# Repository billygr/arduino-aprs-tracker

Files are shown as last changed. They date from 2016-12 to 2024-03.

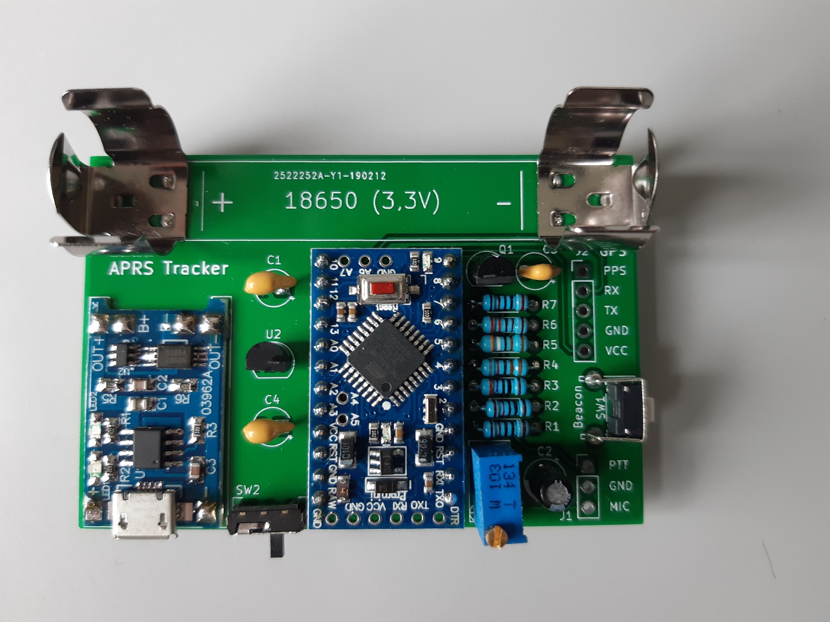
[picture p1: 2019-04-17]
APRS-Tracker_KiCad/Pictures/PCB_soldered_1.jpg

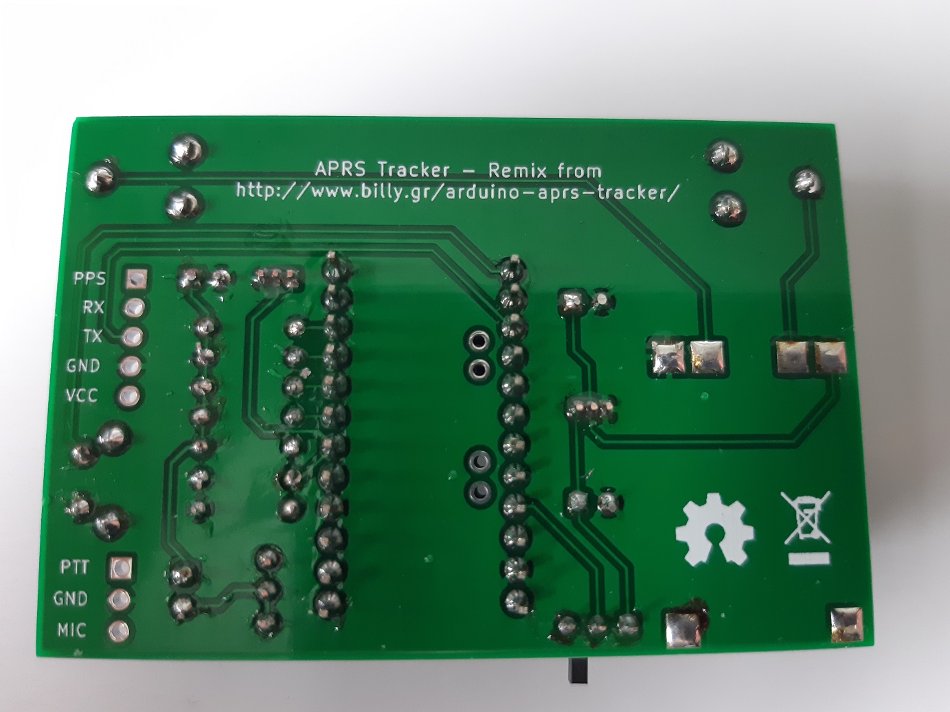
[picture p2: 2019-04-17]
APRS-Tracker_KiCad/Pictures/PCB_soldered_2.jpg

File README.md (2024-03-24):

# arduino-aprs-tracker

Arduino APRS Tracker based on libAPRS with SmartBeaconing

## Hardware
* Arduino Pro Mini 3.3V 8 MHz https://www.adafruit.com/products/2377
* Adafruit Ultimate GPS https://www.adafruit.com/product/746
* or any GPS that can output NMEA (NEO-6M is tested with some minor issues)

## Libraries
* TinyGPS http://arduiniana.org/libraries/tinygps/
* libAPRS (modified) https://github.com/billygr/LibAPRS

## Notes
There are cases where the NEO-6M displays wrong data such as course/altitude. I have trace it to the interrupt of ADC (needed for APRS).
When the interrupt is fired, disrupts the SoftwareSerial so it looses GPS messages.
By default NEO-6M has these messages enabled GSV, RMC, GSA, GGA, GLL, VTG, TXT. 
The GLL is not needed so it is disabled on power on. If you still have issues enable the define, it will switch the NEO-6M on 4800 baud which looks like it fixes it

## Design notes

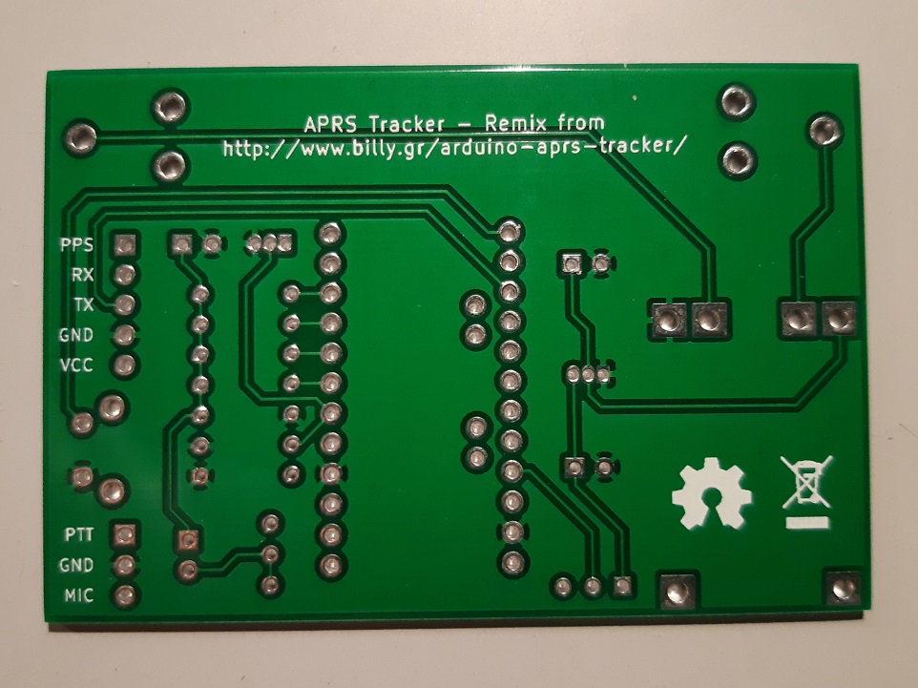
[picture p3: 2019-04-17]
APRS-Tracker_KiCad/Pictures/PCB_2.jpg

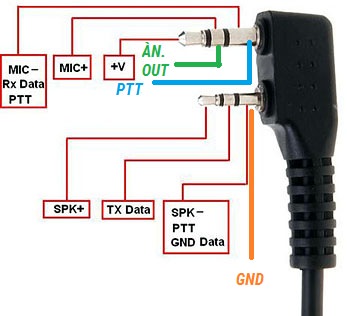
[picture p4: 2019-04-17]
APRS-Tracker_KiCad/Pictures/Baofeng_Plug.jpg

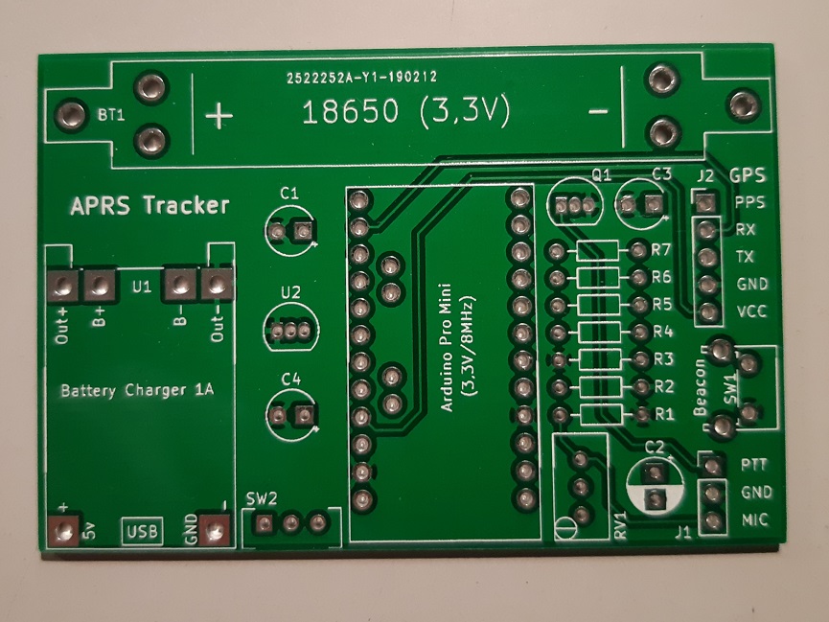
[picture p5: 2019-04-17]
APRS-Tracker_KiCad/Pictures/PCB_1.jpg

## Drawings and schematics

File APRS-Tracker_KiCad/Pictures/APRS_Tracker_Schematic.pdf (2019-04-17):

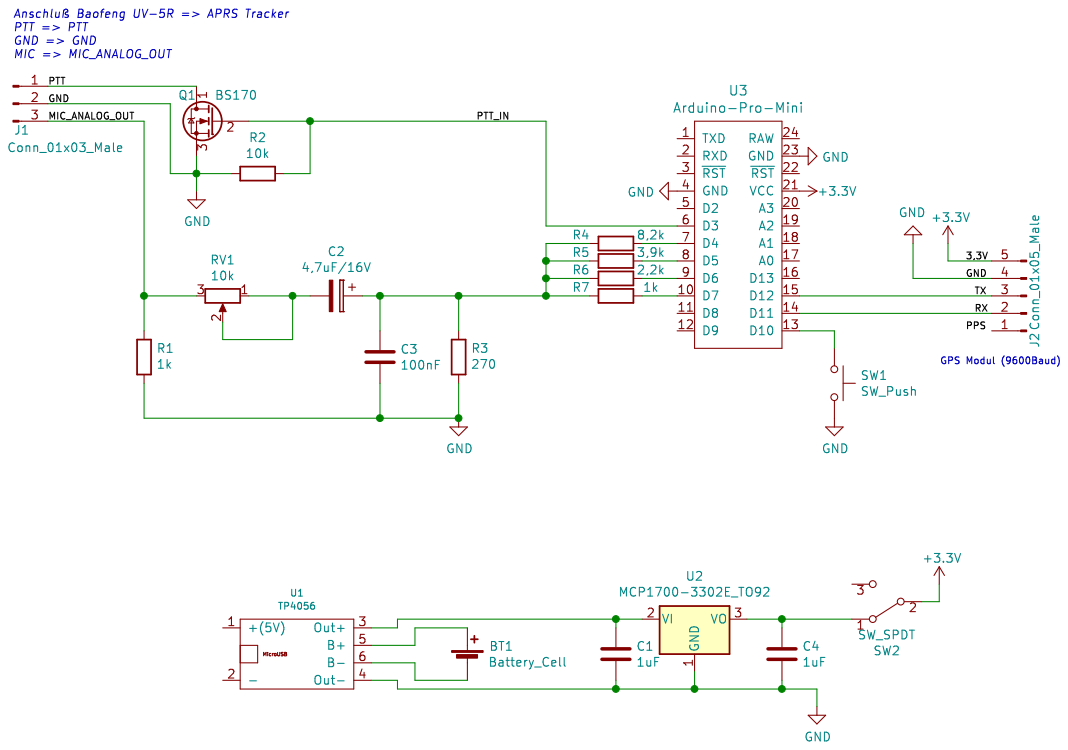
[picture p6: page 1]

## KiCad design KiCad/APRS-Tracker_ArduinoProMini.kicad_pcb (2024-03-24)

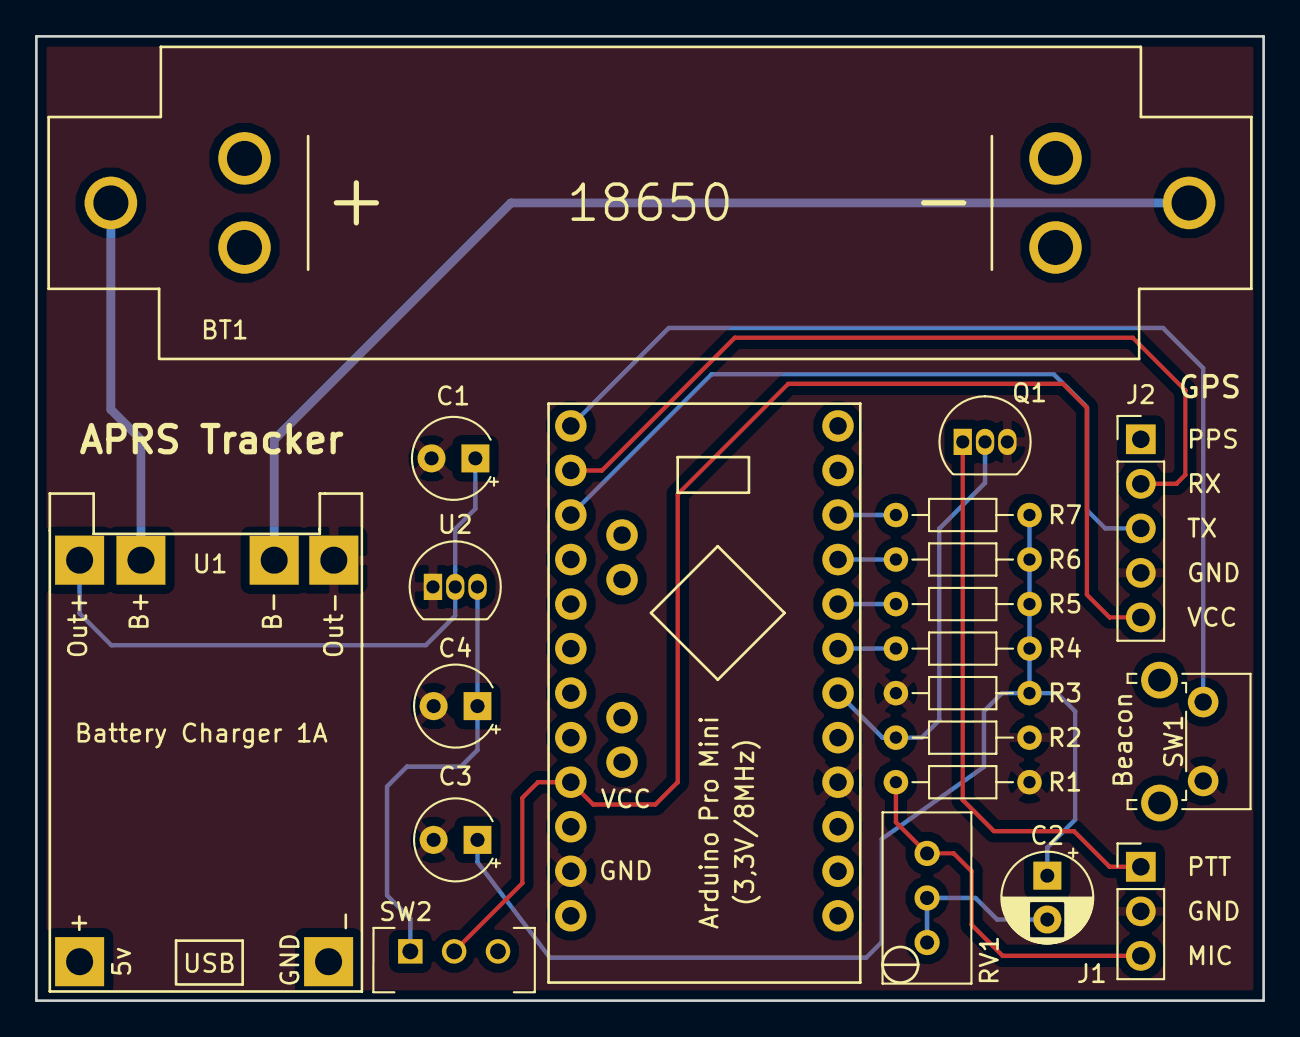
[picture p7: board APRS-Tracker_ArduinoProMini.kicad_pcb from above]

Board: 2 copper layers, 70.0 x 55.0 mm, 21 parts (0 on the bottom side), 18 nets.

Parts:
BT1: Battery_Cell; Battery_ClipHolder_18650
C1, C4: 1uF; CP_Radial_Tantal_D4.5mm_P2.50mm
C2: 4,7uF/16V; CP_Radial_D5.0mm_P2.50mm
C3: 100nF; CP_Radial_Tantal_D4.5mm_P2.50mm
J1: Conn_01x03_Male; PinHeader_1x03_P2.54mm_Vertical
J2: Conn_01x05_Male; PinHeader_1x05_P2.54mm_Vertical
Q1: BS170; TO-92_Inline
R1, R7: 1k; R_Axial_DIN0204_L3.6mm_D1.6mm_P7.62mm_Horizontal
R2: 10k; R_Axial_DIN0204_L3.6mm_D1.6mm_P7.62mm_Horizontal
R3: 270; R_Axial_DIN0204_L3.6mm_D1.6mm_P7.62mm_Horizontal
R4: 8,2k; R_Axial_DIN0204_L3.6mm_D1.6mm_P7.62mm_Horizontal
R5: 3,9k; R_Axial_DIN0204_L3.6mm_D1.6mm_P7.62mm_Horizontal
R6: 2,2k; R_Axial_DIN0204_L3.6mm_D1.6mm_P7.62mm_Horizontal
RV1: 10k; Potentiometer_Bourns_3296W_Vertical
SW1: SW_Push; SW_Tactile_SPST_Angled_PTS645Vx31-2LFS
SW2: SW_SPDT; SW_CuK_JS202011BQN_SPDT_Angled
U1: TP4056; TP4056-18650
U2: MCP1700-3302E_TO92; TO-92_Inline
U3: Arduino-Pro-Mini; Arduino-ProMini

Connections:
+3V3: J2.5, SW2.2, U3.21
/MIC_ANALOG_OUT: J1.3, R1.2, RV1.3
/PTT: J1.1, Q1.1
/PTT_IN: Q1.2, R2.1, U3.6
/RX: J2.2, U3.14
/TX: J2.3, U3.15
GND: C1.2, C3.2, C4.2, J1.2, J2.4, Q1.3, R1.1, R2.2, R3.1, SW1.2, U1.4, U2.1, U3.4, U3.23
unnamed: BT1.1, U1.5
unnamed: BT1.2, U1.6
unnamed: C1.1, U1.3, U2.2
unnamed: C2.1, C3.1, R3.2, R4.2, R5.2, R6.2, R7.2
unnamed: C2.2, RV1.1, RV1.2
unnamed: C4.1, SW2.1, U2.3
unnamed: R4.1, U3.7
unnamed: R5.1, U3.8
unnamed: R6.1, U3.9
unnamed: R7.1, U3.10
unnamed: SW1.1, U3.13

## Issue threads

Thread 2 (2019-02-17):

APRS tracker without GPS module

cookins, 2019-02-17:
Hey there!
Im not exactly programmer, so can somebody help me to edit code for manual GPS coords just.
For me its not necessary to update GPS coords, cuz device located in same spot all time.
Thank you.

billygr, 2019-02-23:
Looking at the code you will need a lot of changes, do you need just one update or updates over fixed intervals ?

cookins, 2019-02-23:
just fixed coords. for all time stationary location.
without GPS module of course.

billygr, 2019-02-24:
Here you go compile test only
https://github.com/billygr/aprs-tracker-without-gps-module

cookins, 2019-02-24:
Thank you :kissing_heart:

Closed 2019-02-24.

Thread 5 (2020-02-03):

How to change aprs beacon timer?

kovalroma, 2020-02-03:
Hello,
I found that tracker send beacon every 1 minutes.
Is it possible to change it to 30 seconds ?
I've changed this line
```
 #define TIMER_MINUTES 30L*1000L
```
But it didn't help.

billygr, 2020-02-04:
Hi ,

you can change directly the interval on this line

aprs_update_timer_id=timer.setInterval(2*TIMER_MINUTES, setAprsUpdateFlag)

Replace 2*TIMER_MINUTES with 30000. I would recommend to go so low , it is way to fast and you will fill the APRS network with messages

kovalroma, 2020-02-04:
Thank you so much!

Closed 2020-02-04.

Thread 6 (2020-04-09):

Timer

Wosacz, 2020-04-09:
Hello, May I have a question about your "timer"? Is it the way how to fix APRS and GPS modul with their problems work together? How it work?

billygr, 2020-04-10:
Hi, I don't understand exactly the question. If you have a GPS fix the timer just fires up and send an APRS location

Closed 2020-07-30.

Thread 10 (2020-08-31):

SmartBeaconing is sending invalid packets after long time continuous working

kovalroma, 2020-08-31:
Hello,
We have tested new SmartBeaconing feature (tested on 2 devices) during long time (few days) continuous work.
We found very strange issues.

During first several days all sending correctly. But later we found that trackers send invalid data
` -9>APZMDM,WIDE1-1,WIDE2-2,qAR,UR5KSH-1:=5036.75N/02614.07E>/A=000746Arduino APRS Tracker `
Should be
` UR5KSH-9>APZMDM,WIDE1-1,WIDE2-2,qAR,UR5KSH-1:=5036.75N/02614.07E>/A=000746Arduino APRS Tracker `

And the second tracker
` UR5KHL-9>APZMDM,UR5KSH-1,WIDE1*,WIDE2-2,qAO,UR5KDK-2:=5044.37N/02603.18E>-16/60/A=000670Arduino APRS Tracker `
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

To fix invalid behavior I restarted device.

I think this error someway connected with buffer overload.

billygr, 2020-09-03:
Still checking it, thanks for reporting it

kovalroma, 2020-09-17:
Was it possible to reproduce the error?

billygr, 2020-09-20:
Nope, i reset it today and will let it there running for 48h again (stationery)

kovalroma, 2020-09-20:
In our case bug appears after 7 days. So, maybe 48h would be not enough.

kovalroma, 2020-10-30:
Hello @billygr
Any news? Does only our setup has such kind of problem? If yes maybe we need to try to change Arduino board.

billygr, 2020-10-30:
Hi,

It is software related for sure but i cannot trace it. What is the Arduino IDE version you are using ? Can you please try with the latest ?

kovalroma, 2021-01-21:
Good morning, hope you are doing well.
After long time we found what's cause problem of irregular distance.
Definitely something wrong with GPS data.

Please look here, this is Arduino terminal:

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

Sometimes GPS send incorrect coordinates (putting zero) to Arduino:
```
Lat: correct_data Lon: 0.00000
Lat: 0.00000 Lon: 0.00000
```

In theory any object could be in such position, but in practice this is almost impossible. Maybe it's good idea to add additional check ? I will explain what I mean.
For instance if distance between 2 coordinates more than 100 km, it's mean that something wrong with GPS data, and in this case just ignore such packet ? Almost all our tracker (3 pieces) has such type of bug.

In additional. The same hardware (Arduino, GPS) works create in previous firmware, without SmartBeacon, where only interval beaconing send. Maybe this problem somehow connected with continuous data transmission between Arduino and GPS in case of SmartBeaconing and interval data transmission in case of interval beaconing ?

Today we are going to upload firmware with latest Arduino and library. I'll let you know about the results.

billygr, 2021-01-22:
Got it , it looks like the invalid is always 0.0000 let me work with it over the weekend and drop this type of location when they arrive from the GPS

kovalroma, 2021-01-22:
This is packet from aprsdirect.com RAW mode. I think at least Lat or Lon is 0.0000.
```
UR5KSH-9>APZMDM,WIDE1-1,WIDE2-2,qAR,UR5KSH-1:=0000.00N/00004.00E>-48/03/A=000662Arduino APRS Tracker
 ```

billygr, 2021-01-22:
Thank you, and the code is from the SmartBeacon branch ?

kovalroma, 2021-01-22:
> Thank you, and the code is from the SmartBeacon branch ?

Yes. It's from SmartBeacon branch.  Master branch works without bugs.

kovalroma, 2021-01-22:
Here is also invalid packet. Retransmitted by several Digipeater, but anyway

```
22.01.2021 20:43:36+01:00: UR5KHL-9>APZMDM,UR5KSH-1*,WIDE1*,UR4PWJ-1*,WIDE2-1,qAS,UR3PDA-9:=5037.58N/02614.70E>-30/70
```

```
22.01.2021 20:46:44+01:00: UR5KHL-9>APZMDM,UR5KSH-1,WIDE1,UR4PWJ-1*,WIDE2-1,qAS,UR3PDA-9:=5037.58N/02614.71E>-10/06
```

This ` -30/70 ` and `-10/06 ` . But should be ` /A=004200 `
It seams that coordinates is correct, but why ` char APRS_comment [36]="/A="; `  was changed? This is mysterious.

kovalroma, 2021-01-24:
Please take a look on this packet
```
UR5KHL-9 to APZMDM-0 via WIDE1-1,WIDE2-2 UI  PID=F0 5037.58N/02614.70E>-22/23./A=004200Arduino APRS Tracker. V=13.5
```
This is decoded APRS packet. After 6 hours we have lot's of packet's with incorrect course and speed data.
This ` -22/23./ ` should be represented as ``` 000/000 or .../... or VVV/VVV ```

APRS reference:
```
The 7-byte CSE/SPD Data Extension can be used to represent the course and
speed of a vehicle or APRS Object.
The course is expressed in degrees (001-360), clockwise from due north. The
speed is expressed in knots. A slash / character separates the two.
For example:
 088/036 represents a course 88 degrees, traveling at 36 knots.
If the course and speed are unknown or not relevant, they can be set to
000/000 or .../... or VVV/VVV.
```
I found that this data are based on following expressions
https://github.com/billygr/arduino-aprs-tracker/blob/de4ff6c1971c3560d853e6b98d39e82cd3298869/arduino-aprs-tracker/arduino-aprs-tracker.ino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

https://github.com/billygr/arduino-aprs-tracker/blob/de4ff6c1971c3560d853e6b98d39e82cd3298869/arduino-aprs-tracker/arduino-aprs-tracker.ino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

But I am not sure,  ` gps.f_course() ` calculated on Arduino with ` TinyGPS ` or this is just received data from satellite ?

kovalroma, 2021-01-24:
This is from TiniGPS
```
case COMBINE(_GPS_SENTENCE_GPRMC, 8): // Course (GPRMC)
      _new_course = parse_decimal();
```
Can you confirm that ` speed_kt ` is received from GPS module. So, Arduino received speed and course in GPRMC message which was calculated on GPS module compute system ?

billygr, 2021-01-25:
Hi,

Let's try to fix it one step at a time. I have added a small check for lat if 0 it will be ignored
Can you please confirm that it is working as expected ?

kovalroma, 2021-01-25:
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

Hey, thanks! I will check new code and let you know.

BTW, we use [Neo-6m GPS module](https://www.u-blox.com/sites/default/files/products/documents/NEO-6_DataSheet_(GPS.G6-HW-09005).pdf). This is quite similar, to Adafruit Ultimate GPS. But much more cheaper.

Also I found this [library ](https://github.com/SlashDevin/NeoGPS) dedicated to work with our hardware.

billygr, 2021-01-25:
Hi,

I am waiting for a one Neo-6m. Use whatever is available, there is a chance that are fake (if coming from china) but still they work . I will look over this code maybe it will help to reduce the ram usage (needed for LibAPRS)

Billy

kovalroma, 2021-01-26:
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

We bought Neo-6m on Aliexpress, so definitely fake. But nevertheless they correctly work with [U-Center](https://www.u-blox.com/en/product/u-center).

Here is our APRS log with new firmware after 8 hours.
For example randomly 10 minutes from 9:30 to 9:40. We got 16 packet.

Problem with incorrect coordinates not found.

Problem with incorrect course/speed is found.
11 packet are correct,
5 packet are not correct.

All the time Arduino is connected and doesn't move.

```
26.01.2021 09:30:10+01:00: UR5KHL-9>APZMDM,WIDE1-1,WIDE2-2,qAR,UR5KSH-1:=5037.59N/02614.71E>/A=004200Arduino APRS Tracker

26.01.2021 09:30:40+01:00: UR5KHL-9>APZMDM,WIDE1-1,WIDE2-2,qAR,UR5KSH-1:=5037.59N/02614.71E>-31/35/A=004200Arduino APRS Tracker

26.01.2021 09:30:43+01:00: UR5KHL-9>APZMDM,UR5KSH-1,WIDE1,UR4PWJ-1*,WIDE2-1,qAS,UR3PDA-9:=5037.59N/02614.71E>-31/35

26.01.2021 09:31:09+01:00: UR5KHL-9>APZMDM,WIDE1-1,WIDE2-2,qAR,UR5KSH-1:=5037.59N/02614.70E>/A=004200Arduino APRS Tracker

26.01.2021 09:31:58+01:00: UR5KHL-9>APZMDM,WIDE1-1,WIDE2-2,qAR,UR5KSH-1:=5037.59N/02614.69E>/A=004200Arduino APRS Tracker

26.01.2021 09:33:28+01:00: UR5KHL-9>APZMDM,WIDE1-1,WIDE2-2,qAR,UR5KSH-1:=5037.59N/02614.71E>/A=004200Arduino APRS Tracker
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
kovalroma, 2021-03-23:
Here full log from second attempt :) .  Chinese GPS module Neo-M8N.

[aprs-log-chines-module-gps.txt](https://github.com/billygr/arduino-aprs-tracker/files/6192439/aprs-log-chines-module-gps.txt)

billygr, 2021-03-24:
i think that you have got fakes, the position jumps as i can see it on the log.

Is it always after 30 minutes ? I mean you can reproduce it  ?

kovalroma, 2021-03-25:
> Is it always after 30 minutes ? I mean you can reproduce it ?

Not sure, will check again.
Meanwhile attached log from [smartbeaconing ](https://github.com/billygr/arduino-aprs-tracker/tree/smartbeaconing)tree with branded Velleman VMA430.
[aprs-log-Velleman VMA430.txt](https://github.com/billygr/arduino-aprs-tracker/files/6206907/aprs-log-Velleman.VMA430.txt)

The same bug after 25/3/2021 17:3:58.
The last digit here
` 25/3/2021 17:4:4 LAT=52150757 LON=21056484 5209.04N/02103.38E Altitude m/ft: 104.80/225`
is `currentcourse`.

kovalroma, 2021-03-25:
This log after I press reset button on arduino
```
25/3/2021 18:8:48 LAT=52150762 LON=21056485 5209.04N/02103.38E Altitude m/ft: 120.40/0
25/3/2021 18:8:49 LAT=52150761 LON=21056483 5209.04N/02103.38E Altitude m/ft: 120.60/0
25/3/2021 18:8:50 LAT=52150761 LON=21056481 5209.04N/02103.38E Altitude m/ft: 120.70/0
25/3/2021 18:8:51 LAT=52150761 LON=21056480 5209.04N/02103.38E Altitude m/ft: 120.90/0
25/3/2021 18:8:52 LAT=52150760 LON=21056479 5209.04N/02103.38E Altitude m/ft: 121.10/0
25/3/2021 18:8:54 LAT=52150760 LON=21056476 5209.04N/02103.38E Altitude m/ft: 121.10/0
25/3/2021 18:8:55 LAT=52150760 LON=21056475 5209.04N/02103.38E Altitude m/ft: 121.50/0
25/3/2021 18:8:56 LAT=52150760 LON=21056475 5209.04N/02103.38E Altitude m/ft: 121.60/0
25/3/2021 18:8:57 LAT=52150760 LON=21056474 5209.04N/02103.38E Altitude m/ft: 121.70/0
25/3/2021 18:8:58 LAT=52150761 LON=21056473 5209.04N/02103.38E Altitude m/ft: 121.80/0
25/3/2021 18:8:59 LAT=52150761 LON=21056473 5209.04N/02103.38E Altitude m/ft: 122.00/0
25/3/2021 18:9:0 LAT=52150761 LON=21056473 5209.04N/02103.38E Altitude m/ft: 122.10/0
25/3/2021 18:9:1 LAT=52150762 LON=21056473 5209.04N/02103.38E Altitude m/ft: 122.10/0
```

Take a look to time stamp.

After I press reset 3 times, it changed to normal
```
25/3/2021 18:11:41 LAT=52150802 LON=21056440 5209.04N/02103.38E Altitude m/ft: 128.30/0
25/3/2021 18:11:42 LAT=52150803 LON=21056439 5209.04N/02103.38E Altitude m/ft: 128.20/0
25/3/2021 18:11:43 LAT=52150803 LON=21056438 5209.04N/02103.38E Altitude m/ft: 128.10/0
25/3/2021 18:11:44 LAT=52150803 LON=21056437 5209.04N/02103.38E Altitude m/ft: 128.00/0
```

kovalroma, 2021-03-25:
Yes, I can reproduced with Velleman VMA430 and [smartbeaconing ](https://github.com/billygr/arduino-aprs-tracker/tree/smartbeaconing) tree.

billygr, 2021-03-26:
i did a long run while displaying the free memory , no mem leaks, of course that doesn't solve you problem

Can you please check this ? https://portal.u-blox.com/s/question/0D52p00008HKEEECA5/psa-fake-ublox-modules-and-potential-ways-to-identify-them mainly the GPTXT

kovalroma, 2021-03-30:
From Velleman VMA430
```
$GPTXT,01,01,02,u-blox ag - www.u-blox.com*50
$GPTXT,01,01,02,HW  UBX-G70xx   00070000 FF7FFFFFo*69
$GPTXT,01,01,02,ROM CORE 1.00 (59842) Jun 27 2012 17:43:52*59
$GPTXT,01,01,02,PROTVER 14.00*1E
$GPTXT,01,01,02,ANTSUPERV=AC SD PDoS SR*20
$GPTXT,01,01,02,ANTSTATUS=OK*3B
$GPTXT,01,01,02,LLC FFFFFFFF-FFFFFFFF-FFFFFFFF-FFFFFFFF-FFFFFFF9*51
```

kovalroma, 2021-03-30:
Chinese module
```
$GNTXT,01,01,02,u-blox AG - www.u-blox.com*4E
$GNTXT,01,01,02,HW UBX-M8030 00080000*60
$GNTXT,01,01,02,EXT CORE 3.01 (d189ff)*68
$GNTXT,01,01,02,ROM BASE 3.01 (107888)*25
$GNTXT,01,01,02,FWVER=ADR 4.11*53
$GNTXT,01,01,02,PROTVER=19.10*11
$GNTXT,01,01,02,MOD=NEO-M8L-0*65
$GNTXT,01,01,02,FIS=0xEF4015 (100111)*58
$GNTXT,01,01,02,GPS;GLO;GAL;BDS*77
$GNTXT,01,01,02,SBAS;IMES;QZSS*49
$GNTXT,01,01,02,GNSS OTP=GPS;GLO*37
$GNTXT,01,01,02,LLC=FFFFFFFF-FFFFFFFF-FFFFFFFF-4FFFFF7E-FFFFFF49*20
$GNTXT,01,01,02,ANTSUPERV=AC *00
$GNTXT,01,01,02,ANTSTATUS=OK*25
$GNTXT,01,01,02,PF=3F7*3A
```

billygr, 2022-03-05:
Just an update.

The issue is not related on your GPS but on the code it self. Yes it reproduce on my NEO-6M also, but only on this device type

It was traced down to the ADC interrupt killing the software serial so it was missing GPS data. I have updated it for the smartbeaconing branch will do the same also here.

billygr, 2024-03-24:
Merged the smartbeaconing branch to master including the fixes

Closed 2024-03-24.

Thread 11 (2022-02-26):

Error in height and continuous sending of packets

ghost, 2022-02-26:
Hello, I see that the height error is a recurring theme. If I load the TinyGPS IDE example, the readings are correct, but with the smartbeaconing code it always shows me 1000000. I guess it could be an error with the data reading or conversion, at one point I put some serialprintln and it started to show me fine, but it didn't last long and it was gone.

Regarding the continuous sending of packets, it enters the update loop and has a hard time getting out, I could see that the course of being in normal values, goes to a negative value and 5 figures.

I currently use a 3.3v Pro mini board and a NEO6

Greetings

billygr, 2022-02-27:
Could you please so kind and test the TinyGPSPlus branch ? It contains the smartbeaconing code but i have not done any real tests. Eventually i will switch to this library in any case

billygr, 2022-02-27:
Can you please check the recent update on the smartbeaconing branch ?

We will be able to narrow it down

billygr, 2022-02-27:
Ok

Two different topics:
Altitude 1000000 comes from TinyGPS when the Altitude is invalid
Course 1000 if the course is invalid

I tried to fix the course issue, in the latest update. I was able to reproduce it locally but now my GPS is not giving a valid course (inside the house) to confirm it

aledorrego, 2022-02-28:
I just uploaded the smartbeaconing update. The continuous sending of packets problem was apparently solved, it only fires eventually by turning, but being without movement. The height still shows 1000000.
If I load the example from the TinyGPS IDE it shows me the height fine.
I currently use IDE 1.8.15
You can see me on aprs.fi as LW7EEA-7

billygr, 2022-03-01:
When stationary the GPS cannot provide a valid course (it jumps left,right) so it will get fired randomly.

The height is not valid that's why you get a 1000000. Will fix that also by ignoring this values

aledorrego, 2022-03-02:
I keep doing tests.

When I uncomment this line

   // Serial.write(c); // uncomment this line if you want to see the GPS data flowing

I see the data that the GPS extracts, but the GPGGA sentence is not seen, which is the one that throws the height and satellite data.

On the other hand, if I uncomment this line

  // uncomment this line to turn on RMC (recommended minimum) and GGA (fix data) including altitude
  //GPS.sendCommand(PMTK_SET_NMEA_OUTPUT_RMCGGA);

it gives me compilation error.

billygr, 2022-03-02:
I have pushed another update to the smartbeaconing branch 5 minutes ago. Can you please do another test ? its more clean/better output etc

billygr, 2022-03-02:
Yes and it will stay in that loop till the altitude is correct

aledorrego, 2022-03-02:
it's fine. comment out that loop, and the height keeps reading 1000000 for many minutes.
Are you sure the library is reading the GPGGA statement?

billygr, 2022-03-02:
Yeap, no changes on the library. It is what TinyGPS reports, the value of 1000000 means invalid altitude

aledorrego, 2022-03-02:
okay.  I don't know what is causing the error in altitude.  when I load the example from the TinyGPS IDE I get the altitude fine and instantly.  That's why I thought that the GPS was not getting all the data.  When I do a c serialprint, which would be the raw GPS data, I never see the GGA statement, nor do I see the height and satellite values.  but well, I appreciate your time and predisposition to try to solve it.  a hug and thanks

billygr, 2022-03-03:
First of all thanks for the hug !!!. I can reproduce it with a NEO 6M here, and i think it is a matter of timing (processing data from the module). The reason the TinyGPS example that it is working is that it is pretty simple.

After a reset of the arduino, even with the GPS on a fix, i will get a lot of lines with 255 satellites and invalid latitude

Still looking at it

billygr, 2022-03-03:
The issue is the RAM usage, excluding the libaprs part the code behaves as expected (so your GPS it not faulty)

billygr, 2022-03-05:
Updated.

Not RAM usage but the ADC ISR killing the SoftwareSerial... give it a try

Its not the best solution to reduce the speed of the GPS to 4800 but it is more stable

aledorrego, 2022-03-05:
Well, I just uploaded the new code, but unfortunately it's still the same.

Do not worry

03/05/2022 12:53:18 -38.726333-61.287624 0.00   0.19  3843.57S/06117.25W 1000000.00/4200 0 0 1325
03/05/2022 12:53:19 -38.726333-61.287624 0.00   0.15  3843.57S/06117.25W 1000000.00/4200 0 0 1649
03/05/2022 12:53:20 -38.726333-61.287624 0.00   0.11  3843.57S/06117.25W 1000000.00/4200 0 0 2189
03/05/2022 12:53:21 -38.726333-61.287624 0.00   0.37  3843.57S/06117.25W 1000000.00/4200 0 0 677
03/05/2022 12:53:23 -38.726337-61.287624 0.00   0.13  3843.58S/06117.25W 1000000.00/4200 0 0 1881
03/05/2022 12:53:26 -38.726337-61.287624 0.00   0.22  3843.58S/06117.25W 1000000.00/4200 0 0 1109
03/05/2022 12:53:27 -38.726337-61.287624 0.00   0.11  3843.58S/06117.25W 1000000.00/4200 0 0 2189
03/05/2022 12:53:29 -38.726337-61.287628 0.00   0.00  3843.58S/06117.25W 1000000.00/4200 0 0 0
03/05/2022 12:53:30 -38.726337-61.287624 0.00   0.54  3843.58S/06117.25W 1000000.00/4200 0 0 476

billygr, 2022-03-05:
Give it some time and eventually the 1000000 altitude gets fixed

aledorrego, 2022-03-05:
I have no luck, more than 30 minutes working and still the same.

billygr, 2022-03-06:
Give it a try with 4800 baud, mine is sitting on my desk and recovers after 2-3 minutes

aledorrego, 2022-03-06:
Ok. Intentaré nuevamente. Entendí que la última actualización ya estaba en 4800, no es así? Lo cargue tal cual está en el archivo. O te lo que modificar algo?

billygr, 2022-03-06:
Only if you remove the comments from the define neo-6m. If you want to revert it to 9600 you will need to power cycle it (after disabling the define again )

aledorrego, 2022-03-06:
Now yes my friend!!!! After so much work it works!!! what a genius....
Now I can see the height and the number of satellites I receive without problems. In fact this last update improved the course, no more high values are seen.
I am going to work on showing in the APRS comment, instead of the height in feet, that it shows me the number of satellites.
Very grateful for all your time and wisdom, it's really a pleasure to have dealt with you.

billygr, 2022-03-07:
Just remember that it is a workaround for the real issue . At least you have something to play with

billygr, 2024-03-24:
Merged smartbeaconing including the workaround to master

Closed 2024-03-24.

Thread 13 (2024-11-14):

I'm having trouble at PTT

uguraltinsoy, 2024-11-14:
I am using the LibAPRS library and my problem is that the default PTT time is too short and the signal is not fully transmitted. How can I bypass it and make my own continuous TX, the signal is much cleaner.

https://www.youtube.com/watch?v=PrCiLKZh58M

billygr, 2024-11-16:
Give it a try with the Preamble and Tail on the void setup
// APRS_setPreamble(350);
// APRS_setTail(50);

uguraltinsoy, 2024-11-17:
Jeg tester ved hjælp af soundmodem og afsk1200dec, men der er ingen forbedring, desværre spekulerer jeg på, om det ikke fungerer for mig, jeg rejste også i byen i det åbne område, jeg kan ikke falde til APRS.fi

billygr, 2024-11-17:
Can you please use English on your comments ? Thank you

uguraltinsoy, 2024-11-17:
Sorry, I am testing using soundmodem and afsk1200dec, but there is no improvement, unfortunately, I wonder if it is not working for me, I also traveled in the open area in the city, it does not fall to APRS.fi

uguraltinsoy, 2024-11-17:
They are connected to the same ground line

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

billygr, 2024-11-17:
Give it a try by grounding manually the PTT on the module and press BUTTON_PIN 10 for a manual update on the Arduino

If it works correctly you will see your message on the aprs.fi . and the problem is beetween the PTT and the Arduino.

I assume that you see the messages on the serial of Arduino , right ?

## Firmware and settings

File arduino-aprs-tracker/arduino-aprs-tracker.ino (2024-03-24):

/***
 * Arduino APRS Tracker (aat) with Arduino Pro Mini 3.3V/8 MHz
 * Install the following libraries through Arduino Library Manager
 * - TinyGPS by Mikal Hart
 * -
 * -
 ***/

#include <SoftwareSerial.h>
#include <TinyGPS.h>
#include <LibAPRS.h>

// Enable this define NEO6M if you are constantly getting wrong data,
// the ADC ISR triggers during SoftwareSerial so we miss data coming from GPS
// (for some reason only on this type of GPS and only when running on 9600 bps)
//#define NEO6M

// Manual update button
#define BUTTON_PIN 10

// GPS SoftwareSerial
// Shares pins with (MISO 12/ MOSI 11) used for SPI
#define GPS_RX_PIN 12
#define GPS_TX_PIN 11
TinyGPS gps;
SoftwareSerial GPSSerial(GPS_RX_PIN, GPS_TX_PIN);

// LibAPRS
#define OPEN_SQUELCH false
#define ADC_REFERENCE REF_3V3

// PPT_PIN is defined on libAPRS/device.h
//#define PPT_PIN 3

// GPS_FIX_LED A3/D17
#define GPS_FIX_LED A3

// APRS settings
char APRS_CALLSIGN[] = "NOCALL";
const int APRS_SSID = 5;
char APRS_SYMBOL = '>';


// SmartBeaconing(tm) Setting  http://www.hamhud.net/hh2/smartbeacon.html implementation by LU5EFN

#define LOW_SPEED 5 // [km/h]
#define HIGH_SPEED 90

#define SLOW_RATE 1750 // [seg]
#define FAST_BEACON_RATE  175

#define TURN_MIN  30
#define TURN_SLOPE  240
#define MIN_TURN_TIME 20

//long instead of float for latitude and longitude
long lat = 0;
long lon = 0;

int speed_kt = 0;
int currentcourse = 0;
int ialtitude_feet = 0;

unsigned long lastTX = 0, tx_interval = 0;
int previouscourse = 0, turn_threshold = 0, courseDelta = 0;

bool newData = false;
// buffer for conversions
#define CONV_BUF_SIZE 16
static char conv_buf[CONV_BUF_SIZE];

/*****************************************************************************************/
void setup()
{
  Serial.begin(115200);
  GPSSerial.begin(9600);

#ifdef NEO6M
  GPSSerial.print("$PUBX,41,1,0007,0003,4800,0*13\r\n");
  GPSSerial.begin(4800);
  GPSSerial.flush();
#endif

  // Reduce NMEA messages
  disableGPGLL();
  pinMode(BUTTON_PIN, INPUT_PULLUP);
  pinMode(GPS_FIX_LED,OUTPUT);

  Serial.println(F("Arduino APRS Tracker"));

  APRS_init(ADC_REFERENCE, OPEN_SQUELCH);
  APRS_setCallsign(APRS_CALLSIGN,APRS_SSID);
  APRS_setSymbol(APRS_SYMBOL);

  Serial.print(F("Callsign:     ")); Serial.print(APRS_CALLSIGN); Serial.print(F("-")); Serial.println(APRS_SSID);
  Serial.print(F("Free RAM:     ")); Serial.println(freeMemory());
  Serial.println(F("Date       Time     Latitude  Longitude  Course Speed APRS Lat/Lon       Altitude   Course current/Delta/turn_threshold"));
  Serial.println(F("                    (deg)     (deg)      (deg)  (Km/h)DDMM.mmN/DDDMM.mmW (m/ft)                "));
  Serial.println(F("-----------------------------------------------------------------------------------------------"));
}

static void smartdelay(unsigned long ms)
{
  unsigned long start = millis();
  do
  {
    while (GPSSerial.available())
      {
        if (gps.encode(GPSSerial.read())) newData = true;

      }
  } while (millis() - start < ms);
}

static void print_int(unsigned long val, unsigned long invalid, int len)
{
  char sz[32];
  if (val == invalid)
    strcpy(sz, "*******");
  else
    sprintf(sz, "%ld", val);
  sz[len] = 0;
  for (int i=strlen(sz); i<len; ++i)
    sz[i] = ' ';
  if (len > 0)
    sz[len-1] = ' ';
  Serial.print(sz);
  smartdelay(0);
}

static void print_float(float val, float invalid, int len, int prec)
{
  if (val == invalid)
  {
    while (len-- > 1)
      Serial.print('*');
    Serial.print(' ');
  }
  else
  {
    Serial.print(val, prec);
    int vi = abs((int)val);
    int flen = prec + (val < 0.0 ? 2 : 1); // . and -
    flen += vi >= 1000 ? 4 : vi >= 100 ? 3 : vi >= 10 ? 2 : 1;
    for (int i=flen; i<len; ++i)
      Serial.print(' ');
  }
  smartdelay(0);
}

static void print_date(TinyGPS &gps)
{
  int year;
  byte month, day, hour, minute, second, hundredths;
  unsigned long age;
  gps.crack_datetime(&year, &month, &day, &hour, &minute, &second, &hundredths, &age);
  if (age == TinyGPS::GPS_INVALID_AGE)
    Serial.print(F("********** ******** "));
  else
  {
    char sz[32];
    sprintf(sz, "%02d/%02d/%02d %02d:%02d:%02d ",
        month, day, year, hour, minute, second);
    Serial.print(sz);
  }
  smartdelay(0);
}
/*****************************************************************************************/
void loop()
{
  float flat, flon;

  unsigned long age=0;

  float faltitude_meters=0, fkmph=0;

  // Process GPS data every second (or so)
  smartdelay(1000);
  gps.get_position(&lat, &lon, &age);

  while (age == TinyGPS::GPS_INVALID_AGE)
  {
    // It is not an ideal check but provides a good indication, could be no fix/GPS is not connected/GPS is sending garbage
    Serial.println(F("No fix detected"));
    smartdelay(1000);
    gps.get_position(&lat, &lon, &age);
  }

  if (newData && lat !=0)
  {
    // Parse twice the location with both float and long. Using float helps to paste it directly to google maps for troubleshooting
    gps.get_position(&lat, &lon, &age);
    gps.f_get_position(&flat, &flon, &age);

    // TinyGPS reports TinyGPS::GPS_INVALID_F_ALTITUDE = 1000000.0 for invalid altitude
    faltitude_meters = gps.f_altitude(); // +/- altitude in meters

    // Quick fix to ignore wrong data in calculations
    if (int (faltitude_meters) > 30000) faltitude_meters =0;
    ialtitude_feet = int(faltitude_meters*3.281);  // integer value of altitude in feet

    fkmph = gps.f_speed_kmph(); // speed in km/h

    // Quick fix to ignore wrong data in calculations
    if (int (fkmph) > 300) fkmph = 0;

    speed_kt = (int) gps.f_speed_knots(); // speed in knots for APRS

    // TinyGPS reports TinyGPS::GPS_INVALID_F_ANGLE = 1000.0 for invalid course
    currentcourse = (int) gps.f_course();

    // Quick fix to ignore wrong data in calculations
    if (currentcourse > 360 || currentcourse < 0) currentcourse=0;

    // Calculate difference of course to smartbeacon
    courseDelta = (int) ( previouscourse - currentcourse );
    courseDelta = abs (courseDelta);
    if (courseDelta > 180) {
      courseDelta = courseDelta - 360;
    }
    courseDelta = abs (courseDelta) ;

    digitalWrite(GPS_FIX_LED, !digitalRead(GPS_FIX_LED)); // Toggle the GPS_FIX_LED on/off

    print_date(gps);
    print_float(flat, TinyGPS::GPS_INVALID_F_ANGLE, 10, 6);
    print_float(flon, TinyGPS::GPS_INVALID_F_ANGLE, 11, 6);
    print_float(gps.f_course(), TinyGPS::GPS_INVALID_F_ANGLE, 7, 2);
    print_float(fkmph, TinyGPS::GPS_INVALID_F_SPEED, 6, 2);
    Serial.print(deg_to_nmea(lat, true));Serial.print(F("/"));Serial.print(deg_to_nmea(lon, false));
    Serial.print(F(" ")); Serial.print(faltitude_meters);Serial.print(F("/"));Serial.print(ialtitude_feet);

    // Based on HamHUB Smart Beaconing(tm) algorithm
    if ( fkmph < LOW_SPEED ) {
      tx_interval = SLOW_RATE *1000L;
    }
    else if ( fkmph > HIGH_SPEED) {
      tx_interval = FAST_BEACON_RATE  *1000L;
    }
    else {
    // Interval inbetween low and high speed
      tx_interval = ((FAST_BEACON_RATE * HIGH_SPEED) / fkmph ) *1000L ;
    }

    turn_threshold = TURN_MIN + TURN_SLOPE / fkmph;

    Serial.print(F(" "));Serial.print(currentcourse);Serial.print(F(" "));Serial.print(courseDelta);
    Serial.print(F(" "));Serial.println(turn_threshold);

    if (courseDelta > turn_threshold ){
      if ( millis() - lastTX > MIN_TURN_TIME *1000L){
        Serial.println(F("DEBUG: APRS UPDATE because of millis() - lastTX > MIN_TURN_TIME *1000L"));
        locationUpdate();
        lastTX = millis();
      }
    }

    previouscourse = currentcourse;
    // tx_internal with default values 1750000 milliseconds/1750 seconds/29.16 minutes
    if ( millis() - lastTX > tx_interval) {
      Serial.println(F("DEBUG: APRS UPDATE because of millis() - lastTX > tx_interval"));
      locationUpdate();
      lastTX = millis();
    }

    if (digitalRead(BUTTON_PIN)==0)
    {
      while(digitalRead(BUTTON_PIN)==0) {}; //debounce
      Serial.println(F("MANUAL UPDATE"));
      locationUpdate();
    }
  }
  newData = false;
}

/*****************************************************************************************/
void aprs_msg_callback(struct AX25Msg *msg) {
}

/*****************************************************************************************/
void locationUpdate() {
//Altitude in Comment Text — The comment may contain an altitude value,
//in the form /A=aaaaaa, where aaaaaa is the altitude in feet. For example:
//A=001234. The altitude may appear anywhere in the comment.
//Source: APRS protocol
//Which means /A=000XXXArduino APRS Tracker (29 characters)

  char comment []= "Arduino APRS Tracker";
  char temp[8];
  char APRS_comment [32]="/A=";

  // Convert altitude in string and pad left
  sprintf(temp, "%06d", ialtitude_feet);
  strcat(APRS_comment,temp);
  strcat(APRS_comment,comment);
  //Serial.println(APRS_comment);

  APRS_setLat((char*)deg_to_nmea(lat, true));
  APRS_setLon((char*)deg_to_nmea(lon, false));

  APRS_setSpeed(speed_kt);
  APRS_setCourse(currentcourse);

  // turn off SoftSerial to stop interrupting tx
  GPSSerial.end();

  // TX
  APRS_sendLoc(APRS_comment, strlen(APRS_comment));

  // read TX LED pin and wait till TX has finished. LibAPRS has TX_LED defined on (PB5), i use LED_BUILTIN on my version as TX_LED
  while(digitalRead(LED_BUILTIN));

  // start SoftSerial again
#ifdef NEO6M
   GPSSerial.begin(4800);
#else
   GPSSerial.begin(9600);
#endif
}

/*****************************************************************************************/
/*
**  Convert degrees in long format to APRS string format
**  DDMM.hhN for latitude and DDDMM.hhW for longitude
**  D is degrees, M is minutes and h is hundredths of minutes.
**  http://www.aprs.net/vm/DOS/PROTOCOL.HTM
*/
char* deg_to_nmea(long deg, boolean is_lat) {
  bool is_negative=0;
  if (deg < 0) is_negative=1;

  // Use the absolute number for calculation and update the buffer at the end
  deg = labs(deg);

  unsigned long b = (deg % 1000000UL) * 60UL;
  unsigned long a = (deg / 1000000UL) * 100UL + b / 1000000UL;
  b = (b % 1000000UL) / 10000UL;

  conv_buf[0] = '0';
  // in case latitude is a 3 digit number (degrees in long format)
  if( a > 9999) {
    snprintf(conv_buf , 6, "%04lu", a);
  } else {
    snprintf(conv_buf + 1, 5, "%04lu", a);
  }

  conv_buf[5] = '.';
  snprintf(conv_buf + 6, 3, "%02lu", b);
  conv_buf[9] = '\0';
  if (is_lat) {
    if (is_negative) {conv_buf[8]='S';}
    else conv_buf[8]='N';
    return conv_buf+1;
    // conv_buf +1 because we want to omit the leading zero
    }
  else {
    if (is_negative) {conv_buf[8]='W';}
    else conv_buf[8]='E';
    return conv_buf;
    }
}

void disableGPGLL()
{
  const char *msg = "PUBX,40,GLL,0,0,0,0,0";

  // find checksum
  int checksum = 0;
  for (int i = 0; msg[i]; i++)
    checksum ^= (unsigned char)msg[i];

  // convert and create checksum HEX string
  char checkTmp[8];
  snprintf(checkTmp, sizeof(checkTmp)-1, "*%.2X", checksum);

  // send to module
  GPSSerial.print("$");
  GPSSerial.print(msg);
  GPSSerial.println(checkTmp);
  GPSSerial.flush();
}

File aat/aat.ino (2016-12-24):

// Arduino APRS Tracker (aat) with Arduino Pro Mini 3.3V/8 MHz
// Based on https://github.com/sh123/aprs_tracker
// 
#include <SoftwareSerial.h>
#include <SimpleTimer.h>
#include <TinyGPS.h>
#include <LibAPRS.h>

// Single shot button
#define BUTTON_PIN 10

// GPS SoftwareSerial
// Shares pins with (MISO 12/ MOSI 11) used for SPI
#define GPS_RX_PIN 12
#define GPS_TX_PIN 11

// LibAPRS
#define OPEN_SQUELCH false
#define ADC_REFERENCE REF_3V3

// APRS settings
#define APRS_CALLSIGN "NOCALL"
#define APRS_SSID 5
#define APRS_SYMBOL ">"

// Timer
#define TIMER_DISABLED -1

TinyGPS gps;
SoftwareSerial GPSSerial(GPS_RX_PIN, GPS_TX_PIN);
SimpleTimer timer;

char aprs_update_timer_id = TIMER_DISABLED;
bool send_aprs_update = false;
//long instead of float for latitude and longitude
long lat = 0;
long lon = 0;

int year=0;
byte month=0, day=0, hour=0, minute=0, second=0, hundredths=0;
unsigned long age=0;

// buffer for conversions
#define CONV_BUF_SIZE 20
static char conv_buf[CONV_BUF_SIZE];

void setup()  
{
  Serial.begin(115200);
  GPSSerial.begin(9600);

  pinMode(BUTTON_PIN, INPUT_PULLUP);
  
  Serial.println(F("Arduino APRS Tracker"));

  //GPS.sendCommand(PMTK_SET_NMEA_OUTPUT_RMCGGA);
  //GPS.sendCommand(PMTK_SET_NMEA_UPDATE_1HZ);
  //GPS.sendCommand(PGCMD_ANTENNA);

  APRS_init(ADC_REFERENCE, OPEN_SQUELCH);
  APRS_setCallsign(APRS_CALLSIGN,APRS_SSID);
  APRS_setSymbol(APRS_SYMBOL);
  
  aprs_update_timer_id=timer.setInterval(2L*60L*1000L, setAprsUpdateFlag);
}

void loop()
{
  bool newData = false;

  // For one second we parse GPS data
  for (unsigned long start = millis(); millis() - start < 1000;)
  {
    while (GPSSerial.available())
    {
      char c = GPSSerial.read();
      // Serial.write(c); // uncomment this line if you want to see the GPS data flowing
      if (gps.encode(c)) // Did a new valid sentence come in?
        newData = true;
    }
  }

  if (newData)
  {
    gps.crack_datetime(&year, &month, &day, &hour, &minute, &second, NULL, &age);
    gps.get_position(&lat, &lon, &age);

    Serial.print(static_cast<int>(day)); Serial.print("/"); Serial.print(static_cast<int>(month)); Serial.print("/"); Serial.print(year);
    Serial.print(" "); Serial.print(static_cast<int>(hour)); Serial.print(":"); Serial.print(static_cast<int>(minute)); Serial.print(":"); Serial.print(static_cast<int>(second));Serial.print(F(" "));

    Serial.print(F("LAT="));Serial.print(lat);
    Serial.print(F(" LON="));Serial.print(lon);

    Serial.print(F(" "));
    Serial.print(deg_to_nmea(lat, true));
    Serial.print(F("/"));

    Serial.println(deg_to_nmea(lon, false));

  if (digitalRead(BUTTON_PIN)==0)
  {
    while(digitalRead(BUTTON_PIN)==0) {}; //debounce
    Serial.println(F("MANUAL UPDATE"));
    locationUpdate();
  }
  
  if (send_aprs_update) {
    Serial.println(F("APRS UPDATE"));
    locationUpdate();
    send_aprs_update = false;
  }

  }
  timer.run();
}

void aprs_msg_callback(struct AX25Msg *msg) {
}

void locationUpdate() {
const char *comment = "Arduino APRS Tracker";

//  APRS_setLat("5530.80N");
//  APRS_setLon("01143.89E");
  APRS_setLat((char*)deg_to_nmea(lat, true));
  APRS_setLon((char*)deg_to_nmea(lon, false));
      
  // turn off SoftSerial to stop interrupting tx
  GPSSerial.end();
  
  // TX
  APRS_sendLoc(comment, strlen(comment));
 
  // read TX LED pin and wait till TX has finished (PB5) digital write 13 LED_BUILTIN
  while(bitRead(PORTB,5));

  // start SoftSerial again
  GPSSerial.begin(9600);
}

// https://github.com/sh123/aprs_tracker/blob/master/aprs_tracker.ino
/*
**  Convert degrees in long format to NMEA string format
**  DDMM.hhN for latitude and DDDMM.hhW for longitude
*/
char* deg_to_nmea(long deg, boolean is_lat) {
  unsigned long b = (deg % 1000000UL) * 60UL;
  unsigned long a = (deg / 1000000UL) * 100UL + b / 1000000UL;
  b = (b % 1000000UL) / 10000UL;
  // DDMM.hhN/DDDMM.hhW
  // http://www.aprs.net/vm/DOS/PROTOCOL.HTM
  conv_buf[0] = '0';
  snprintf(conv_buf + 1, 5, "%04u", a);
  conv_buf[5] = '.';
  snprintf(conv_buf + 6, 3, "%02u", b);
  conv_buf[9] = '\0';
  if (is_lat) {
    conv_buf[8] = deg > 0 ? 'N': 'S';
    return conv_buf + 1;
  } else {
     conv_buf[8] = deg > 0 ? 'E': 'W';
     return conv_buf;
  }
}

void setAprsUpdateFlag() {
  send_aprs_update = true;
}

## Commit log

2017-04-03 Fixes aprs conversion for negative lat/long
    [arduino-aprs-tracker.ino]
2017-08-15 Possible fix for wrong APRS icon
    [arduino-aprs-tracker.ino]
2017-12-28 Fix for 3 digit lattitude
    [arduino-aprs-tracker.ino]
2019-04-14 KiCad & Gerber Files for PCB
    [APRS-Tracker_ArduinoProMini-B.Cu.gbl, APRS-Tracker_ArduinoProMini-B.Mask.gbs, APRS-Tracker_ArduinoProMini-B.SilkS.gbo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]
2019-04-16 Pictures added
    [APRS-Tracker_ArduinoProMini-B.Cu.gbl, APRS-Tracker_ArduinoProMini-B.Mask.gbs, APRS-Tracker_ArduinoProMini-B.SilkS.gbo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]
2019-09-19 Moved the ino under a folder to fix issues with travis
    [arduino-aprs-tracker.ino]
2020-01-05 Fix warnings
    Use %lu for unsigned long variables.
    [arduino-aprs-tracker.ino]
2020-01-12 Added GPS fix led on A3 pin
    [arduino-aprs-tracker.ino]
2020-01-12 Added the SimpleTimer to the project from commit b30890b8f7046bf3b0258e5870e5dda78ac5c71a since the Arduino Library manager contains a complete different project/version
2020-04-20 fixing the buffer overflow...
    [arduino-aprs-tracker.ino]
2021-01-25 Potential fix for 0 on lat
    [arduino-aprs-tracker.ino]
2022-02-27 Possible fix for wrong course data
    [arduino-aprs-tracker.ino]
2022-02-27 Fix the usual equal test...
    [arduino-aprs-tracker.ino]
2022-02-27 Fix eventually the multiple updates
    [arduino-aprs-tracker.ino]
2022-03-05 Catch the issue with the ADC interrupt killing the SoftSerial for NEO-6M
    [arduino-aprs-tracker.ino]
2024-03-24 Converted to Kicad 7.x changed designators
    [APRS-Tracker_ArduinoProMini.kicad_sch, APRS-Tracker_ArduinoProMini.sch]
2024-03-24 New file format
    [APRS-Tracker_ArduinoProMini.kicad_pcb]
2024-03-24 Fixing directory structure
    [APRS-Tracker_ArduinoProMini.kicad_pcb, APRS-Tracker_ArduinoProMini.kicad_sch]
2024-03-24 Moved the Kicad 5.x version to archive
    [APRS-Tracker_ArduinoProMini-B.Cu.gbl, APRS-Tracker_ArduinoProMini-B.Mask.gbs, APRS-Tracker_ArduinoProMini-B.SilkS.gbo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]
2024-03-24 Added the missing PCBv1 Kicad files
    [APRS-Tracker_ArduinoProMini.kicad_pcb, APRS-Tracker_ArduinoProMini.sch]
2024-03-24 Added fix LED
    [APRS-Tracker_ArduinoProMini.kicad_sch]
